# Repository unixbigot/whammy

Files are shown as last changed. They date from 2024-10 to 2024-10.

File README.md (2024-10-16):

# Whammy - A bluetooth expression pedal using tilt angle to trigger effects

The Whammy system consists of two pieces of hardware, both of which
are compiled from this repository.    Much of the source code is
common.

The software runs atop the Zephyr real time operating system, and
makes use of an application module for Zephyr named 'ztacx' (also
written by the author of whammy).

The hardware components are

## Whammy Puck

A bluetooth Low-Energy (BLE aka Bluetooth 4, which is a totally
different protocol than older versions of bluetooth) 
peripheral that contains an accelerometer and magnetometer.

In BLE you can think of "peripheral" as meaning "server".
It exposes all the sensors as "characteristics", characteristics being
in essence "pages" that the server can serve.

The puck is battery powered, and attaches to your instrument via a
suction cup.   The battery should last many days (but should be
disconnected when not in use).

Bluetooth characteristics are identified by UUIDs, which can be 
from a standard service profile, or vendor specific.

For ease of use we use the standard "Generic Level" characteristic ID 
to serve the "wham factor".   Many other sensors and details are also
presented.   You can test the puck using the 'nrfConnect' app on android or iphone to
scan for the device and browse these characteristics.  (Note the device will not be
accessible from your phone if something else is already connected to
it, like the receiver).

The puck has an LED.   1 second blink rate means "waiting for
connection", 5 second blink rate means "somebody is connected".

The puck is configured to expose the "X-Axis Acceleration" in
cm/sec/sec as the "generic level".  For tilt this would range from
-980 (normal acceleration due to gravity), through zero (the device is
perfectly flat therefore there is no acceleration in the X-direction),
to 980 (1G or 9.8m/s/s, x-axis aligned straight down).   Under conditions of shock or
shaking acceleration could be much higher (the device is configured
for a max of 2G).

## Whammy Receiver

The receiver has a colour (RGB) LED and a digital-to-analog converter (DAC), built
into the back of a Tip-Ring-Sleeve phono plug.   Sleeve is ground, Tip
is 5-12 volts input, and Ring is analog out (0-to-3.3 volts).

The receiver is intended to plug into the "expression pedal" jack of
any audo effect box.

The receiver acts as a "bluetooth central" device (bluetooth-speak for
client).   The receiver scans for a peripheral named "whammy puck"
(LED will be orange).   When it connects (LED goes green) it looks for
the "Generic Level" characteristic, and monitors its value.   Whenever
the value changes the receiver blinks the LED blue and updates the
DAC.

The receiver converts the "generic level" range of [-980, 980] to the
DAC's parameter range [0,4095].  The DAC expresses its parameter as a
voltage, from [0, 3.3v].

It is intended that your effect be configured to treat this analog
voltage as an input to its effect processing.

A test fixture is supplied which uses a USB cable to supply 5 volts to
the receiver, and displays the output voltage on a voltmeter.

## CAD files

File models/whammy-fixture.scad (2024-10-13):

length=25.4;
width=20.5;
clearance=0.2;
$fn=60;
fuz=0.1;fuzz=2*fuz;
include <lozenge.scad>

module post() {
    cylinder(d=5,h=8);
    cylinder(d=4,h=width+fuzz);
    translate([0,0,15]) cylinder(d=8,h=10);
}


module base() {
    difference() {
	lozenge(l=length*2,w=width*2,h=width,r=5);
	translate([5,5,-fuz]) post();
	translate([length*2-5,5,-fuz]) post();
	translate([5,2*width-5,-fuz]) post();
	translate([length*2-5,2*width-5,-fuz]) post();
	translate([length/2,width/2,5]) lozenge(l=length+2*clearance,w=width+2*clearance,h=width,r=2);
	translate([-fuz,width/2,5]) {
	    //cube([length*1.5+fuz,width,1]);
	    translate([0,1.5,-2.5]) cube([length/2+fuzz, width-3,5]);
	}
	translate([length,width,width]) rotate([0,90,0]) cylinder(d=width*0.75,h=3*length,center=true);
    }
}

//base();
intersection() {
    base();
    translate([-fuz,-fuz,-fuz]) cube([3*length,3*width,7.5]);
}

translate([3*length,0,0]) intersection() {
    translate([0,0,-7.5-fuz]) base();
    translate([-fuz,-fuz,0]) cube([3*length,3*width,width]);
}

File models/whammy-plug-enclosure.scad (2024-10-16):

// Fully parametric box for 3D printing
// v4b
// http://www.thingiverse.com/thing:1918169
//
// Original box based on:
// http://tinyurl.com/oznh2p4
//
// Ventilation holes based on:
// http://www.thingiverse.com/thing:1826360

// Configure below
//
/* [Box parameters] */
// Length of box in mm
length = 50;   //[10:254]
// Width of box in mm
width = 32;    //[10:254]
// Height of box in mm
tall = 13;      //[10:254]
// Wall thickness of box in mm
thick = 1.6;      //[1:15]
// Depth of lip on lid in mm
lDepth = 2;     //[1:15]
// Corner radius; 0 = four square corners
cRadius = 5;   //[0:25]   
// Fancy: Square two opposing corners; 0=no, 1=yes (must be using cRadius)
sqCorners = 1;  //[0,1]

/* [Vent Parameters] */
// Vent hole size in mm; 0 = no vents
hSize = 0;      //[0:15]
// Hole Spacing in mm; must be > 0
hSpace = 1;     //[1:15]
// Vent hole type; 0=round, 1=square
hType = 0;      //[0,1]
//
// Configure above

/* [Hidden] */
//fn=200;            // 40 fragments per cicle; comment for draft mode
//$fn=60;
$fs=0.3;
fuz=0.1; fuzz=2*fuz;

// Draw Box
module post() {
/*     difference() {
	  cylinder(d=6, h=6);
	  cylinder(d=2, h=6.5);
     }
*/
     cylinder(d=5,h=1.2);
     cylinder(d=2.4, h=3);
}

module box() {
    translate([cRadius, cRadius, 0]){
	// Create a hollow box
	difference() {
	    // Create box shape
	    roundedBox(length,width,tall,cRadius,sqCorners);
	    // Create negative box shape, smaller by wall thickness plus clearance
	    translate([thick,thick,thick]) { 
		minkowski() { roundedBox(length-(thick*2),width-(thick*2),tall,cRadius,sqCorners);
		    sphere(r=0.4);
		}
		
		// Add vent holes to long sides
		gutterSpace=max(floor(tall*.2),thick*2,cRadius+hSize);
		if (hSize>0) addVentHoles(
		    length,     				// Panel Width
		    tall,						// Panel Height
		    gutterSpace,                // Gutter Width
		    gutterSpace,                // Gutter Height
		    hSize,						// Hole Radius
		    hSpace,					    // Hole Spacing
		    width+0.02,					// Hole Length
		    -(cRadius)-(thick+0.01),	// X Location
		    -gutterSpace,	            // Y Location
		    hType						// Hole Type
		    );
	    }
	    // cut openings in box	
	    //translate([(width-12)/2-cRadius,-cRadius-0.1,thick+2]) cube([12,10,6]);
	    translate([width/2-cRadius,6-cRadius,-fuz]) cylinder(d=10-1,h=5);
	    
	}
    }
    // Add mounting posts inside box
    //translate([(width-9)/2, 10, thick]) post();
    //translate([(width+9)/2, 10, thick]) post();
    translate([4, length-32-thick, 0]) cube([width-12,thick,6]);
}
box();

module lid() {
// Draw Box Lid
// Shift along-side first box
    translate([(width*2)+(10-cRadius), cRadius, 0]) {
	mirror([1,0,0]) {
	    difference() {
		union() {
		    // Create lid
		    roundedBox(length,width,thick,cRadius,sqCorners);
		    // Create lip on top of lid
		    difference() {
			// Create lip shape
			translate([thick,thick,thick]) {
			    roundedBox(length-(thick*2),width-(thick*2),lDepth,cRadius,sqCorners);}
                        // Create negative shape, smaller by wall thickness
                        // (add 0.01 to depth to bypass rendering bug)
                        translate([(thick*2),(thick*2),thick+0.01]) {
                            roundedBox(length-(thick*4),width-(thick*4),lDepth,cRadius,sqCorners);}    
		    }
		}

		// Cut holes in lid
		//translate([width/2-cRadius,length/2-cRadius,thick/2]) cube([15,24,4*thick],center=true);
        	    translate([width/2-cRadius-7,9-cRadius,-fuz]) cylinder(d=4,h=5);

            }
	}
    }
}

//lid();

// Render box according to parameters
module roundedBox(length, width, tall, radius, sqCorners)
{
	if (radius==0) {
		// Draw regular cube
		cube(size=[width,length,tall]);
	} else {
		// Draw rounded corner cube
		diam=2*radius;

		// Draw base rounded shape
		minkowski() {
			cube(size=[width-diam,length-diam, tall/2]);
			cylinder(r=radius, h=tall/2);
		}

        // Square opposing corners
		if (sqCorners==1) {
			// Corner cube bottom right
			translate([width-diam,-radius,0]) {cube(size=[radius,radius,tall]);}

			// Corner cube top left
			translate([-radius,length-diam,0]) {cube(size=[radius,radius,tall]);}  
		}
	}
}

// Ventillate opposing panels Y-axis panels
module addVentHoles (pWidth, pHeight, gWidth, gHeight, hSize, hSpace, hLength, xLoc, yLoc, hType) {
	hSpacing = hSpace + hSize;
    mainRowHoles = floor((pWidth - (2 * gWidth)) / hSpacing);
    rows = floor((pHeight - (2 * gHeight)) / hSpacing);

    for (n = [0:rows]) {
        for (i = [0:mainRowHoles]) {
            // If we're on an even-number row, then we put holes across the panel
            if (n % 2 == 0)
                translate([
					xLoc,
					yLoc+(i*hSpacing)+(gWidth),
					(n*hSpacing)+gHeight])
					
					rotate([0,90,0])
                    // Choose square or round hole
					if (hType==0) {
						cylinder(h=hLength, r=hSize/2);
					} else {
						translate([0,0,hLength/2]) cube(size=[hSize,hSize,hLength], center=true);
					}	

            // If we're on an odd-number row then we offset the holes, and drop one
            if ((n % 2 == 1) && (i<mainRowHoles)) // This drops the hole
				translate([
					xLoc,
					yLoc+(i*hSpacing)+(gWidth)+(hSpacing/2),
					(n*hSpacing)+gHeight]) 
					
					rotate([0,90,0])
					// Choose square or round hole
					if (hType==0) {				 
						cylinder(h=hLength, r=hSize/2);
					} else {
						translate([0,0,hLength/2]) cube(size=[hSize,hSize,hLength], center=true);
					}	
        }
    }
}

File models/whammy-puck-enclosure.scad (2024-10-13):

/* [Size] */

// length of circuit board
length = 21;

// width of circuit board
width = 32;

// height of circuit board
height=4+2.6;

// height of battery holder
battheight = 2.6;

// corner radius
radius=1;

// fit allowance between base and lid
fit=0.2;

/* [Wall thicknesses] */
side=1.2;
bottom=1.2;
lidbottom=5;
top=0;
rim = 2;

/* [Options] */

// place magnets on outside of case
magnets = "none"; // [none:No magnets,inside:magnets inside case,outside:magnets outside case]

// hole for LED
led_hole = true;

// hole for suction cup
keyhole = true;

// include holes for programming cable
pogo=false;

// length of magnet
maglength = 20;

// height of magnet
magheight = 6;

// width of magnet
magwidth = 4.4;

// fit allowance for magnet socket
magfit = 0.4;

// suction cup keyhole size
keyhole_large = 8;
keyhole_small = 5;
keyhole_depth = 2;



/* [Hidden] */
led_inset_x=4;
led_inset_y = 7;

lidheight=height-bottom+lidbottom;

fuz=0.1; 
fuzz=2*fuz;
$fn=60;

module lozenge(l,w,h,r) {
    hull() {
        translate([r,r,0]) cylinder(r=r,h=h);
        translate([l-r,r,0]) cylinder(r=r,h=h);
        translate([l-r,w-r,0]) cylinder(r=r,h=h);
        translate([r,w-r,0]) cylinder(r=r,h=h);
    }
}

module hollow_lozenge(l,w,h,r=radius,s=side,b=bottom,t=top) {
    difference() {
	lozenge(l,w,h,r);
	translate([s,s,b]) lozenge(l-2*s,w-2*s,h-b-t,r);
    }
}

module hollow_lozenge_id(l,w,h,r,s=side,b=bottom,t=top) {
    difference() {
	lozenge(l+2*s,w+2*s,h+b+t,r+s);
	translate([s,s,b]) lozenge(l,w,h+fuzz,r);
    }
}

module base(){
// inner shell
    difference() {
        union() {
            if (magnets=="inside") {
		// magnets at end
                hollow_lozenge_id(length, width+2*magwidth+2*side, height, radius);
                translate([side+radius,side,bottom]) cube([length-2*radius,magwidth,height-battheight-bottom]);
                translate([side+radius,side+magwidth+side+width+side,bottom]) cube([length-2*radius,magwidth,height-battheight-bottom]);
                translate([0,side+magwidth,0]) cube([length+2*side,side,bottom+height]);
                translate([0,width+magwidth+2*side,0]) cube([length+2*side,side,bottom+height]);
                translate([-side-fit,-side-fit,0]) hollow_lozenge(
                    length+2*(side+fit+side), 
                    width+2*(magwidth+side+side+fit+side), 
                    rim, 
                    radius+(side+fit+side),
                    side+fit,
                    bottom
                );

            } else if (magnets=="outside") {
		// magnets at sides, outside case
                hollow_lozenge_id(length, width+2*magwidth+2*side, height, radius);
                translate([-side-fit,-side-fit,0]) hollow_lozenge(length+2*(side+fit+side), width+2*(side+fit+side), bottom, radius+(side+fit+side),2*side,bottom);
            }
	    else {
		// no magnets
                hollow_lozenge_id(length, width, battheight, radius);
	    }

	    // base to provide seal against lid
            translate([-side-fit,-side-fit,0]) hollow_lozenge(length+2*(side+fit+side), width+2*(side+fit+side), bottom, radius+(side+fit+side),2*side,bottom);
        }
        if (led_hole) {
            translate([side+length-led_inset_x,side+magwidth+side+width-led_inset_y,bottom/2]) cube([1.6,1.6,2*bottom+2*fuzz],center=true);
        }
	if (magnets == "inside") {
	    // cut out to allow lifting the PCB
	    translate([-fuzz,side+magwidth+side,bottom+battheight]) cube([length+2*side+2*fuzz,width,height-battheight+fuzz]);
	}
        
        if (pogo) {
            translate([side+length-4,side+1,-fuzz]) {
                for (i=[0:5]) {
                    translate([-2*i,0,0]) cylinder(d=1,h=2*bottom+2*fuzz);
                }
            }
        }
        
    }
}

module vertical_text(t, size) {
     rotate([90,180,0]) {
          linear_extrude(height=0.8) {
               text(text=t,
                    size = size,
                    //font = "Verdana:style=Bold"
                    font = "Avenir Next Condensed:style=Demi Bold"
                 );
          }    
     }
}

module magbox() {
    difference() {
	cube([maglength+magfit+2*side, magwidth+magfit+2*side, magheight+bottom]);
	translate([side,side,-fuzz]) cube([maglength+magfit,magwidth+magfit,magheight+fuzz]);
    }
}

module lid() {
    difference() {
        union() {
    // outer shell
        if (magnets=="outside") {
            hollow_lozenge_id(l=length+2*(side+fit),w=width+2*(side+fit),h=lidheight,r=radius+(side+fit),b=lidbottom);
        } else if (magnets=="inside") {
            hollow_lozenge_id(l=length+2*(side+fit),w=width+2*(side+magwidth)+2*(side+fit),h=lidheight,r=radius+(side+fit),b=lidbottom);
        } else {
	    ll = length+2*(side+fit);
	    lw = width+2*(side+fit);
	    echo (ll=ll,lw=lw,height=height,side=side,bottom=bottom,lidbottom=lidbottom,lidheight=lidheight);
	    	
            hollow_lozenge_id(l=ll,w=lw,h=height,r=radius+(side+fit),b=lidbottom);
        }
       
        if (magnets=="outside") {
            overlap = 1;
            translate([side,lidwidth_outer/2-12,0]) rotate([0,0,90]) magbox();
            translate([lidlength_outer-overlap,lidwidth_outer/2-12,0]) rotate([0,0,90]) scale([1,-1,1]) magbox();
        }
        //translate([-2,lidwidth_outer/2-12,0]) cube([2+overlap,2,lidheight]);
        //translate([-2,lidwidth_outer/2+10,0]) cube([2+overlap,2,lidheight]);
        //translate([lidlength_outer-overlap,lidwidth_outer/2-12,0]) cube([2+overlap,2,lidheight]);
        //translate([lidlength_outer-overlap,lidwidth_outer/2+10,0]) cube([2+overlap,2,lidheight]);

        //translate([width-3,0,7]) vertical_text(" f742d1",5);
    }
    if (keyhole) {
           translate([2*side+length/2,side+width/2,-fuz]) {
                cylinder(d=keyhole_large, h=lidbottom+fuzz);
		hull() {
		    cylinder(d=keyhole_small, h=lidbottom+fuzz);
		    translate([0,-keyhole_large/2-keyhole_small/2,0]) cylinder(d=keyhole_small, h=lidbottom+fuzz);
		}
		translate([0,0,3]) 
		hull() {
		    cylinder(d=keyhole_large, h=lidbottom-3+fuzz);
		    translate([0,-keyhole_large/2-keyhole_small/2,0]) cylinder(d=keyhole_large, h=lidbottom-3+fuzz);
		}
            }
        }

    }
}


rotate([0,0,90]) base();
translate([2*length+5,-side,0]) rotate([0,0,90]) lid();

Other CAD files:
models/whammy-receiver-box.scad

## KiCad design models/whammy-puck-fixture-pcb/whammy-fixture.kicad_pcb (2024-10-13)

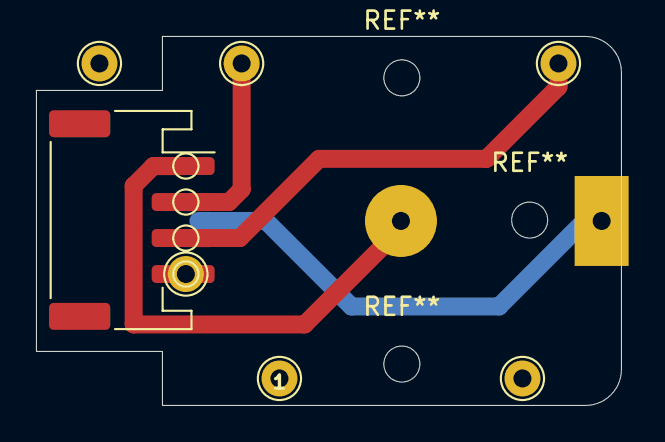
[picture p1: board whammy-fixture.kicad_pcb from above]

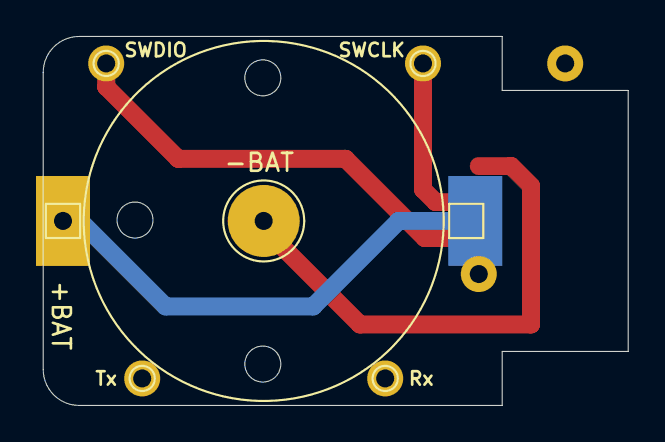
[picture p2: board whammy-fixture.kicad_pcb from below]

Board: 2 copper layers, 32.5 x 20.5 mm, 11 parts (7 on the bottom side), 4 nets.

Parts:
J2, J3: +BAT; TestPoint_Pad_1.5x1.5mm
J4: -BAT; TestPoint_Pad_D4.0mm
TP1: GND; TestPoint_Pad_D1.0mm
TP2: VDD; TestPoint_Pad_D1.0mm
TP3, TP10: SWDIO; TestPoint_Pad_D1.0mm
TP4: SWDCLK; TestPoint_Pad_D1.0mm
TP11: SWCLK; TestPoint_Pad_D1.0mm
TP12: Tx; TestPoint_Pad_D1.0mm
TP13: Rx; TestPoint_Pad_D1.0mm

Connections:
+BATT: J2.1, J3.1, TP2.1
-BATT: J4.1, TP1.1
/SWCLK: TP4.1, TP11.1
/SWDIO: TP3.1, TP10.1

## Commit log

2024-10-13 Sender and receiver for the 'whammy' wireless instrumental expression pedal
    [whammy-fixture.kicad_pcb, whammy-fixture.scad, whammy-puck-enclosure.scad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]
2024-10-16 Add readme, commit final code updates
    [whammy-plug-enclosure.scad]
